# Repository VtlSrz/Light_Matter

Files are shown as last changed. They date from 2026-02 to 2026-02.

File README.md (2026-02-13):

# 📸 Light_Matter

Це DIY проект компактного та точного цифрового експонометра для плівкових фотокамер. Проект базується на мікроконтролері **ESP32-C3 Super Mini** та високоточному датчику освітленості **BH1750**.

Пристрій розроблено як сучасну заміну старим селеновим експонометрам або для використання з камерами, що не мають вбудованого заміру експозиції.

## ✨ Особливості та можливості

* **Режими роботи:**
* **Пріоритет діафрагми (Aperture Priority):** Ви обираєте діафрагму — пристрій підбирає витримку.
* **Пріоритет витримки (Shutter Priority):** Ви обираєте час витримки — пристрій підбирає діафрагму.

* **Широкий діапазон налаштувань:**
* **ISO:** 6 – 12800 (підтримка як сучасних, так і старих плівок).
* **Діафрагма (F):** f/0.7 – f/64 (включаючи вінтажні значення типу f/3.5, f/6.3).
* **Витримка (T):** 1/8000 с – 30 с.

* **Калібрування (EV Shift):** Можливість програмної корекції експозиції (від -3.0 EV до +3.0 EV) для компенсації особливостей простроченої плівки або похибок затвора камери.
* **Інформативний дисплей:**
* Відображення поточних LUX та розрахованого EV.
* Індикація застосованої експокорекції.
* Зручний інтерфейс з великими цифрами.

* **Меню налаштувань:**
* Регулювання яскравості дисплея (5 рівнів).
* Стиль відображення батареї (Іконка / Відсотки / Вольтаж).
* Налаштування таймера сну (Deep Sleep).
* Налаштування орієнтації єкрану.
* Можливість оновлення через WIFI (Elegant OTA).

* **Енергоефективність:**
* Використання Deep Sleep режиму ESP32.
* Автоматичне збереження всіх налаштувань в енергонезалежну пам'ять (Preferences/EEPROM).

* **Живлення:** LiPo акумулятор з можливістю зарядки та моніторингу напруги.

## 🛠 Компоненти (BOM)

| Компонент | Кількість | Примітка |
| --- | --- | --- |
| **ESP32-C3 Super Mini** | 1 | Основний контролер |
| **OLED SSD1306** | 1 | 0.96", 128x64, I2C |
| **BH1750** | 1 | Датчик освітленості (модуль) |
| **LX-LCBST** | 1 | Плата 2-в-1: зарядка LiPo + підвищувач на 5V |
| **LiPo Акумулятор** | 1 | 3.7V, 500mAh (або аналогічний) |
| **Тактова кнопка** | 2 | Керування (Menu / Change) |
| **Резистор 100 kΩ** | 2 | Для дільника напруги (моніторинг батареї) |
| **Дроти, корпус** | - | Для монтажу |

## 🔌 Схема підключення (Pinout)

### 1. Периферія

| Компонент | Пін компонента | Пін ESP32-C3 | Примітка |
| --- | --- | --- | --- |
| **OLED & BH1750** | SDA | **GPIO 8** | Шина I2C |
| | SCL | **GPIO 9** | Шина I2C |
| | VCC | 3.3V | Живлення логіки |
| | GND | GND | Земля |
| **Кнопка Menu** | Pin 1 | **GPIO 2** | Вхід в меню / Вибір параметра |
| | Pin 2 | GND | |
| **Кнопка Change** | Pin 1 | **GPIO 3** | Зміна значення |
| | Pin 2 | GND | | 

### 2. Система живлення та моніторингу батареї

Для живлення використовується плата **LX-LCBST**, яка заряджає акумулятор та підвищує напругу до 5V для стабільної роботи ESP32.

* **Акумулятор (LiPo):** Підключається до входів `BAT+` та `BAT-` плати LX-LCBST.
* **Живлення ESP32:** Вихід `VOUT` (5V) плати LX-LCBST підключається до піна `5V` (або VCC) на ESP32. Земля — спільна.
* **Вимірювання заряду:** Реалізовано через дільник напруги (2 резистори по 100 кОм), підключений безпосередньо до клем акумулятора (до підвищувача напруги).

```
   [LiPo BAT+] ----+---- [Резистор 100k] ---- GPIO 0 (ADC)
                   |           |
                   |     [Резистор 100k] ---- GND
                   |           |
             [LX-LCBST IN+]    

```

## 📖 Інструкція користувача

exponometer_scheme

## 🖥️ Інтерфейс користувача (UI)

Пристрій використовує монохромний OLED дисплей 128x64. Навігація інтуїтивно зрозуміла і здійснюється двома кнопками.
Параметри обираються нопкою **MENU** (верхня), зміна значень — кнопкою **NEXT** (нижня).
**Вибір параметра:** Коротке натискання **MENU** переміщує курсор `>` циклічно:

### 1. Головний екран (Режим вимірювання)

На головному екрані відображаються поточні показники датчика та параметри експозиції. Курсор `>` вказує на параметр, який зараз можна змінити.

**Приклад 1: Пріоритет діафрагми (F), EV Shift вимкнено, індикація заряду (Volt)**

```text
+--------------------------+
| lux540    EV12     4.01V |  <- Верхній статус-бар
|                          |
|    T 1/500               |  <- Розрахована витримка
| >  F 5.6                 |  <- Активний параметр (Діафрагма)
|                          |
|                  ISO 200 |  <- Чутливість
+--------------------------+

```

**Приклад 2: Пріоритет витримки (T), ввімкнено EV Shift (+1.0), індикація щаряду %**
Якщо застосована експокорекція (для старої плівки), її значення з'являється над ISO.

```text
+--------------------------+
| lux250    EV10       95% |
|                          |
| >  T 1/60                |  <- Активний параметр (Витримка)
|    F 4.0                 |  <- Розрахована діафрагма
|                     +1.0 |  <- Індикатор EV Shift
|                  ISO 400 |  <- ISO обрано (інверсний колір)
+--------------------------+

```

---

### 2. Меню налаштувань
Щоб увійти в налаштування, натисніть та утримуйте кнопку **MENU** протягом **2 секунд**. 
Обраний пункт підсвічується інверсією (біла смуга, чорний текст).

**Приклад 3: Початок списку меню**

```text
+--------------------------+
|     --- SETTINGS ---     |  <- Заголовок
|   Calib EV: +1.0         |  <- Обраний пункт (Експокорекція) * **Calib EV:** Експокорекція для старих плівок (від -3.0 до +3.0). Якщо значення відмінне від 0, над ISO з'явиться індикатор (напр. `+1.0`).
| [ Bright: 3            ] |  <- Обраний пункт (Яскравість) * **Bright:** Яскравість дисплея (1 — мін, 5 — макс).
|   Bat Ind: Volt          |  <- Обраний пункт (Заряд) * **Bat Ind:** Вигляд індикатора батареї (Icon / % / Voltage).
|   Sleep: Never           |  <- Обраний пункт (СОН) * **Sleep:** Таймер автовимкнення (від 3 сек до 1 години або вимкнено).
+--------------------------+

```

**Приклад 4: Прокрутка меню вниз (активація WiFi)**
Коли ви рухаєтесь нижче 4-го пункту, меню прокручується.

```text
+--------------------------+
|     --- SETTINGS ---     |
|   Sleep: 1 min           |
|   Rotate: 0 deg          |  <- Обраний пункт (Орієнтація) * **Rotate:** Переворот на 180*, зміна орієнтації дисплея (0-180*) .
| [ WiFi Service         ] |  <- Обраний пункт (Оновлення) * **WiFi Service:** Запуск вайфай точки доступу, оновлення прошивки пристрою.
|   EXIT / BACK            |  <- Обраний пункт (Назад) * **EXIT / BACK:** Плвернення на головний єкран, авто-вихід із меню налаштувань - 10сек, Всі налаштування зберігаються після вимкнення.
+--------------------------+

```

---

### 3. Режим WiFi Service (Оновлення прошивки)

Цей екран з'являється після активації "WiFi Service" в меню. Він показує дані для підключення для OTA-оновлення.

```text
+--------------------------+
| --- WIFI SERVICE ---     |
|                          |
| SSID: Light_Matter       |
| PASS: 12345678           |
| IP:   192.168.4.1        |
|                          |
| [ PRESS MENU TO EXIT ]   |
+--------------------------+

```
Створюється вайфай точка доступу з імʼям - Light_Matter  та паролем - 12345678 . 
Після підключення потрібно ввести в браузері в поле url  - 192.168.4.1/update , 
Відкриється веб сторінка для оновлення прошивки .bin файлами. 
Натиск кнопки Menu або Next повертає до головного єкрану. 

##  Зарядка

Для живлення пристрою використовується lipo аккумулятор на 350мА. Час роботи - до 7 годин. 
Зарядка - 5V 1A блочком. Час зарядки 30хв. При зарядці на нижній кришці горить червоний led, при повній зарядці led горить синім кольором. 
Можна заряджати від павербанку, підтримується роботаа експонометра під час зарядки. 

## 💻 Прошивка

Проект написано в середовищі **Arduino IDE**. та використанням Gemini. 

### Необхідні бібліотеки:

Встановіть наступні бібліотеки через Library Manager:

1. **Adafruit SSD1306** (by Adafruit)
2. **Adafruit GFX Library** (by Adafruit)
3. **BH1750** (by Christopher Laws)
4. **OneButton** (by Matthias Hertel)

### Налаштування плати в Arduino IDE:

* **Board:** ESP32C3 Dev Module
* **USB CDC On Boot:** Enabled
* **Flash Mode:** DIO

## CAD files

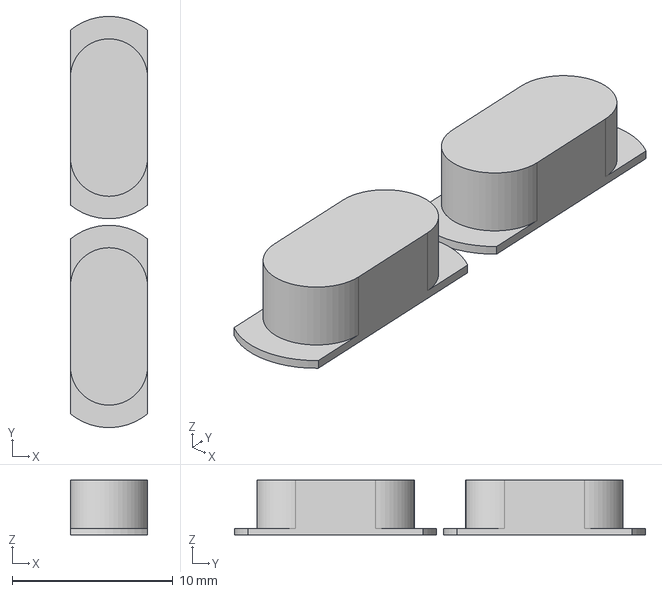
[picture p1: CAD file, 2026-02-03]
3d/buttons.step
4.80 x 25.6 x 3.40 mm

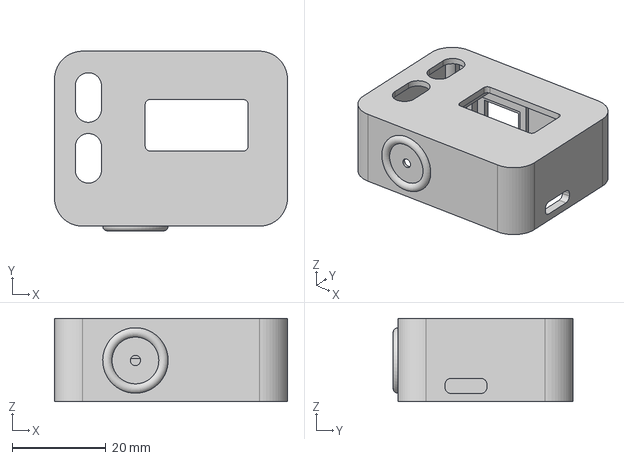
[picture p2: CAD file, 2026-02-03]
3d/case.step
49.8 x 38.4 x 17.8 mm

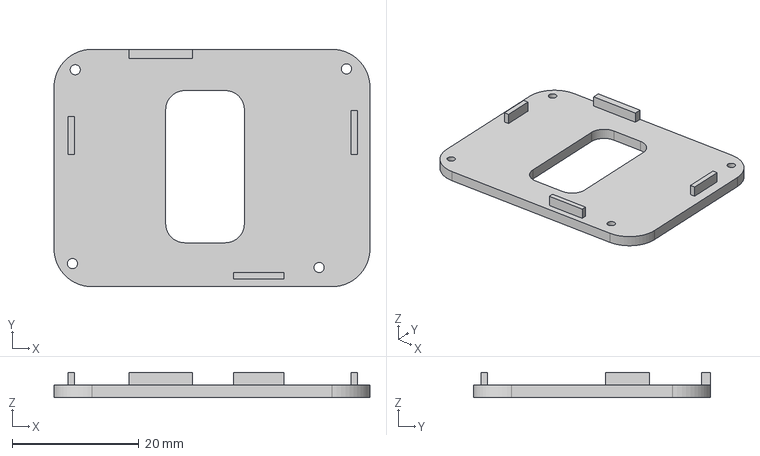
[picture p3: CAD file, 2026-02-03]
3d/back.step
49.8 x 37.4 x 4.00 mm

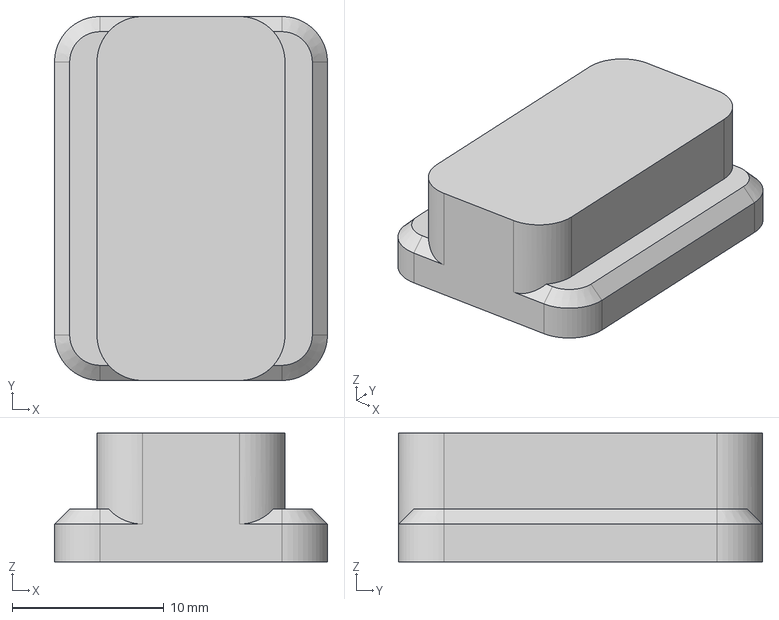
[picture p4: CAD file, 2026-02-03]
3d/shoe.step
18.0 x 24.0 x 8.50 mm

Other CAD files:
3d/front.step

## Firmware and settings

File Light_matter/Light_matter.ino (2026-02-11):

#include <Wire.h>
#include <Adafruit_GFX.h>
#include <Adafruit_SSD1306.h>
#include <BH1750.h>
#include <OneButton.h>
#include <Preferences.h>

// --- WIFI & OTA ---
#include <WiFi.h>
#include <WebServer.h>
#include <ElegantOTA.h>

// --- ПІНИ ---
#define PIN_BATTERY 0
#define PIN_BTN_MENU 1    
#define PIN_BTN_CHANGE 2  

// --- ДИСПЛЕЙ ---
#define SCREEN_WIDTH 128
#define SCREEN_HEIGHT 64
Adafruit_SSD1306 display(SCREEN_WIDTH, SCREEN_HEIGHT, &Wire, -1);

// --- ДАТЧИК ---
BH1750 lightMeter;

// --- ПАМ'ЯТЬ ---
Preferences prefs;

// --- WEB SERVER ---
WebServer server(80);

// --- КНОПКИ ---
OneButton btnMenu(PIN_BTN_MENU, true);
OneButton btnChange(PIN_BTN_CHANGE, true);

// --- СТАНИ ---
enum AppState { STATE_MAIN, STATE_MENU, STATE_WIFI_SERVICE };
AppState currentState = STATE_MAIN;

// --- ЗМІННІ ---
const float dividerRatio = 2.0; 
int selectedIndex = 1; 
int lockMode = 1; 

float currentLux = 0;     
float accumulatedLux = 0; 
int sampleCount = 0;      
float currentEV = 0;

// --- НАЛАШТУВАННЯ ---
int settingsBrightness = 2; 
int settingsBatStyle = 0;   
int settingsSleepIdx = 5;   
int settingsEvShift = 0;    
int settingsRotate = 0;     

unsigned long lastActivityTime = 0; 
unsigned long lastLuxUpdate = 0; 

// --- МАСИВИ ---
const float fStops[] = { 0.7, 0.8, 0.9, 0.95, 1.0, 1.1, 1.2, 1.4, 1.6, 1.7, 1.8, 2.0, 2.2, 2.4, 2.5, 2.8, 3.2, 3.5, 4.0, 4.5, 4.8, 5.0, 5.6, 6.3, 6.7, 7.1, 8.0, 9.0, 9.5, 10, 11, 12.5, 13, 14, 16, 18, 19, 20, 22, 25, 29, 32, 36, 40, 45, 51, 57, 64 };
const int fStopCount = sizeof(fStops) / sizeof(fStops[0]);

const float shutterSpeeds[] = { 8000, 6400, 5000, 4000, 3200, 2500, 2000, 1600, 1250, 1000, 800, 640, 500, 400, 320, 250, 200, 160, 125, 100, 80, 60, 50, 40, 30, 25, 20, 15, 13, 10, 8, 6, 5, 4, 3, 2.5, 2, 1.6, 1.3, -1, -1.3, -1.6, -2, -2.5, -3, -4, -5, -6, -8, -10, -13, -15, -20, -25, -30 };
const int shutterCount = sizeof(shutterSpeeds) / sizeof(shutterSpeeds[0]);

const int isoValues[] = { 6, 12, 25, 50, 64, 80, 100, 125, 160, 200, 250, 320, 400, 500, 640, 800, 1000, 1250, 1600, 2000, 2500, 3200, 6400, 12800 };
const int isoCount = sizeof(isoValues) / sizeof(isoValues[0]);

const long sleepTimes[] = { 0, 3000, 5000, 10000, 30000, 60000, 180000, 300000, 600000, 900000, 1800000, 3600000 };
const char* sleepLabels[] = { "Never", "3 sec", "5 sec", "10 sec", "30 sec", "1 min", "3 min", "5 min", "10 min", "15 min", "30 min", "1 hour" };
const int sleepTimesCount = 12;

int isoIdx = 6;       
int apertureIdx = 22; 
int shutterIdx = 18;  

// --- ЗМІННІ МЕНЮ ---
int menuIndex = 0; 
int menuScrollTop = 0; 
const int menuItemsCount = 7; 
const int menuVisibleItems = 4;

// --- ФУНКЦІЇ ---

void setBrightness(int level) {
  int contrast = 0;
  switch(level) {
    case 0: contrast = 1; break;   
    case 1: contrast = 60; break;  
    case 2: contrast = 127; break; 
    case 3: contrast = 190; break; 
    case 4: contrast = 255; break; 
    default: contrast = 127; break;
  }
  display.ssd1306_command(SSD1306_SETCONTRAST);
  display.ssd1306_command(contrast);
}

void applyRotation() {
  if (settingsRotate == 1) display.setRotation(2); 
  else display.setRotation(0);
}

void loadPreferences() {
  prefs.begin("meter", false);
  isoIdx = prefs.getInt("iso", 6);
  apertureIdx = prefs.getInt("aperture", 22);
  settingsBrightness = prefs.getInt("bright", 2);
  settingsBatStyle = prefs.getInt("batstyle", 0);
  settingsSleepIdx = prefs.getInt("sleep", 5); 
  settingsEvShift = prefs.getInt("evshift", 0); 
  settingsRotate = prefs.getInt("rotate", 0);
  
  setBrightness(settingsBrightness);
}

void savePreferences() {
  prefs.putInt("iso", isoIdx);
  prefs.putInt("aperture", apertureIdx);
  prefs.putInt("bright", settingsBrightness);
  prefs.putInt("batstyle", settingsBatStyle);
  prefs.putInt("sleep", settingsSleepIdx);
  prefs.putInt("evshift", settingsEvShift);
  prefs.putInt("rotate", settingsRotate);
}

void goToSleep() {
  display.clearDisplay();
  display.display();
  display.ssd1306_command(SSD1306_DISPLAYOFF);
  savePreferences();
  esp_deep_sleep_enable_gpio_wakeup((1ULL << PIN_BTN_MENU) | (1ULL << PIN_BTN_CHANGE), ESP_GPIO_WAKEUP_GPIO_LOW);
  esp_deep_sleep_start();
}

float getShutterTime(float val) {
  if (val < 0) return abs(val);
  return 1.0 / val;
}

int roundToTen(float val) {
  if (val < 10) return (int)val; 
  return (int)((val + 5.0) / 10.0) * 10;
}

String getEvShiftString() {
  if (settingsEvShift == 0) return "0.0";
  float val = settingsEvShift / 3.0;
  String s = (val > 0) ? "+" : "";
  s += String(val, 1);
  return s;
}

void startWiFiService() {
  WiFi.mode(WIFI_AP);
  WiFi.softAP("Light_Matter", "12345678");
  
  server.on("/", []() {
    server.send(200, "text/plain", "Light Matter OTA Service. Go to /update");
  });

  ElegantOTA.begin(&server);    
  server.begin();
  
  currentState = STATE_WIFI_SERVICE;
}

void stopWiFiService() {
  server.stop();
  WiFi.softAPdisconnect(true);
  WiFi.mode(WIFI_OFF);
  currentState = STATE_MENU; 
}

// --- CALLBACKS ---

void clickMenu() {
  lastActivityTime = millis(); 
  
  if (currentState == STATE_MAIN) {
    if (selectedIndex == 1) selectedIndex = 0;      
    else if (selectedIndex == 0) selectedIndex = 2; 
    else selectedIndex = 1;                         
    calculateExposure(); 
    drawMainScreen();
  } 
  else if (currentState == STATE_MENU) {
    menuIndex = (menuIndex + 1) % menuItemsCount;
    // SCROLL LOGIC
    if (menuIndex >= menuScrollTop + menuVisibleItems) {
      menuScrollTop = menuIndex - menuVisibleItems + 1;
    }
    if (menuIndex == 0) {
      menuScrollTop = 0;
    }
    drawMenuScreen();
  }
  else if (currentState == STATE_WIFI_SERVICE) {
    stopWiFiService();
    drawMenuScreen();
  }
}

void longPressMenu() {
  lastActivityTime = millis();
  
  if (currentState == STATE_MAIN) {
    currentState = STATE_MENU;
    menuIndex = 0;
    menuScrollTop = 0; 
    drawMenuScreen();
  } 
  else if (currentState == STATE_MENU) {
    currentState = STATE_MAIN;
    savePreferences(); 
    calculateExposure();
    drawMainScreen();
  }
  else if (currentState == STATE_WIFI_SERVICE) {
    stopWiFiService();
    drawMenuScreen();
  }
}

void clickChange() {
  lastActivityTime = millis();
  
  if (currentState == STATE_MAIN) {
    if (selectedIndex == 0) isoIdx = (isoIdx + 1) % isoCount;
    else if (selectedIndex == 1) { apertureIdx = (apertureIdx + 1) % fStopCount; lockMode = 1; }
    else if (selectedIndex == 2) { shutterIdx = (shutterIdx + 1) % shutterCount; lockMode = 2; }
    calculateExposure();
    drawMainScreen();
  } 
  else if (currentState == STATE_MENU) {
    // НОВИЙ ПОРЯДОК ПУНКТІВ
    switch(menuIndex) {
      case 0: // EV Shift
        settingsEvShift++; if (settingsEvShift > 9) settingsEvShift = -9; break;
      case 1: // Brightness
        settingsBrightness = (settingsBrightness + 1) % 5; setBrightness(settingsBrightness); break;
      case 2: // Bat Style
        settingsBatStyle = (settingsBatStyle + 1) % 3; break;
      case 3: // Sleep
        settingsSleepIdx = (settingsSleepIdx + 1) % sleepTimesCount; break;
      case 4: // Rotate
        settingsRotate = !settingsRotate; applyRotation(); break;
      case 5: // WiFi
        startWiFiService(); break;
      case 6: // Exit
        currentState = STATE_MAIN; savePreferences(); break;
    }
    if (currentState == STATE_MENU) drawMenuScreen(); 
  }
}

void setup() {
  Wire.begin(8, 9);
  if(!display.begin(SSD1306_SWITCHCAPVCC, 0x3C)) for(;;);
  
  pinMode(PIN_BTN_MENU, INPUT_PULLUP);
  pinMode(PIN_BTN_CHANGE, INPUT_PULLUP);
  
  btnMenu.attachClick(clickMenu);
  btnMenu.attachLongPressStart(longPressMenu);
  btnMenu.setPressTicks(2000); 
  btnChange.attachClick(clickChange);

  loadPreferences();
  applyRotation();

  selectedIndex = 1; 
  lockMode = 1;      
  
  lightMeter.begin(BH1750::CONTINUOUS_HIGH_RES_MODE);
  display.setTextColor(SSD1306_WHITE);
  
  lastActivityTime = millis();
  lastLuxUpdate = millis();
}

void calculateExposure() {
  if (currentLux <= 0) return;
  float ev100 = log10(currentLux / 2.5) / log10(2.0);
  float shiftedEV100 = ev100 - (settingsEvShift / 3.0);
  currentEV = shiftedEV100 + (log10((float)isoValues[isoIdx] / 100.0) / log10(2.0));

  if (lockMode == 1) { 
    float f = fStops[apertureIdx];
    float t_target = (f * f) / pow(2.0, currentEV);
    
    float minDiff = 1000000;
    int bestIdx = 0;
    for (int i = 0; i < shutterCount; i++) {
      float t_array = getShutterTime(shutterSpeeds[i]);
      float diff = abs(t_array - t_target);
      if (diff < minDiff) { minDiff = diff; bestIdx = i; }
    }
    shutterIdx = bestIdx;
  } else {
    float t_seconds = getShutterTime(shutterSpeeds[shutterIdx]);
    float f_target = sqrt(t_seconds * pow(2.0, currentEV));
    
    float minDiff = 100;
    int bestIdx = 0;
    for (int i = 0; i < fStopCount; i++) {
      float diff = abs(fStops[i] - f_target);
      if (diff < minDiff) { minDiff = diff; bestIdx = i; }
    }
    apertureIdx = bestIdx;
  }
}

void drawBattery(int x, int y) {
  float sum = 0; 
  for(int i=0; i<3; i++) sum += analogRead(PIN_BATTERY);
  
  // 3.04 corrected
  float voltage = (sum/3.0 * 3.04 / 4095.0) * dividerRatio;
  
  int percent = map(constrain(voltage * 100, 330, 420), 330, 420, 0, 100);
  
  if (settingsBatStyle == 1) {
    display.setCursor(x - 10, y); 
    display.print(percent); display.print("%");
  } else if (settingsBatStyle == 2) {
    display.setCursor(x - 18, y); 
    display.print(voltage, 2); display.print("V");
  } else {
    display.drawRect(x, y, 16, 8, SSD1306_WHITE);
    display.fillRect(x + 16, y + 2, 2, 4, SSD1306_WHITE);
    int w = map(percent, 0, 100, 0, 12);
    if(w > 0) display.fillRect(x+2, y+2, w, 4, SSD1306_WHITE);
  }
}

void drawMainScreen() {
  display.clearDisplay();
  int headerY = 4;

  // Header
  display.setTextSize(1);
  display.setCursor(0, headerY);
  display.print("lux"); display.print((int)currentLux);
  
  display.setCursor(60, headerY);
  display.print("EV"); display.print((int)currentEV);
  
  if (settingsEvShift != 0) {
    String shiftStr = getEvShiftString();
    int shiftX = 128 - (shiftStr.length() * 6);
    display.setCursor(shiftX, 46); 
    display.print(shiftStr);
  }

  drawBattery(110, headerY);

  int yCenter = 20;
  int xPadding = 12;

  // T
  if(selectedIndex == 2) { display.setCursor(0, yCenter + 4); display.print(">"); }
  display.setTextSize(2);
  display.setCursor(xPadding, yCenter);
  display.print("T ");
  float sVal = shutterSpeeds[shutterIdx];
  if (sVal > 0) { display.print("1/"); display.print((int)sVal); }
  else { display.print(abs(sVal), 1); display.print("\""); }

  // F
  if(selectedIndex == 1) { display.setTextSize(1); display.setCursor(0, yCenter + 26); display.print(">"); }
  display.setTextSize(2);
  display.setCursor(xPadding, yCenter + 22);
  display.print("F ");
  display.print(fStops[apertureIdx], 1); 

  // ISO
  display.setTextSize(1);
  int isoVal = isoValues[isoIdx];
  int charCount = 4; if(isoVal<100) charCount+=2; else if(isoVal<1000) charCount+=3; else if(isoVal<10000) charCount+=4; else charCount+=5;
  int xPos = 128 - (charCount * 6);
  
  display.setCursor(xPos, 56);
  if(selectedIndex == 0) display.setTextColor(SSD1306_BLACK, SSD1306_WHITE);
  display.print("ISO "); display.print(isoVal);
  display.setTextColor(SSD1306_WHITE);

  display.display();
}

void drawWiFiScreen() {
  display.clearDisplay();
  display.setTextSize(1);
  display.setCursor(0, 0);
  display.println("--- WIFI SERVICE ---");
  display.setCursor(0, 12);
  display.println("SSID: Light_Matter");
  display.setCursor(0, 24);
  display.println("PASS: 12345678");
  display.setCursor(0, 36);
  display.println("IP:   192.168.4.1");
  display.fillRect(0, 52, 128, 12, SSD1306_WHITE);
  display.setTextColor(SSD1306_BLACK);
  display.setCursor(15, 54);
  display.print("PRESS MENU TO EXIT");
  display.setTextColor(SSD1306_WHITE);
  display.display();
}

// НОВЕ ІНВЕРСИВНЕ МЕНЮ
void drawMenuScreen() {
  display.clearDisplay();
  
  display.setTextSize(1);
  // Зміщений заголовок
  display.setCursor(20, 4); 
  display.print("--- SETTINGS ---");
  
  int yBase = 14; 
  int lineHeight = 12; 
  int textOffset = 2; // Менший відступ бо нема курсора

  for (int i = 0; i < menuVisibleItems; i++) {
    int itemIndex = menuScrollTop + i;
    
    if (itemIndex >= menuItemsCount) break;

    int yPos = yBase + (i * lineHeight);

    // ІНВЕРСІЯ ВИДІЛЕННЯ
    if (itemIndex == menuIndex) {
      // Малюємо білий прямокутник фону
      display.fillRect(0, yPos - 1, 128, lineHeight, SSD1306_WHITE);
      // Колір тексту - чорний
      display.setTextColor(SSD1306_BLACK);
    } else {
      // Колір тексту - білий
      display.setTextColor(SSD1306_WHITE);
    }

    display.setCursor(textOffset, yPos);

    // НОВИЙ ПОРЯДОК ПУНКТІВ
    switch (itemIndex) {
      case 0:
        display.print("Calib EV: ");
        display.print(getEvShiftString());
        break;
      case 1:
        display.print("Bright: ");
        display.print(settingsBrightness + 1);
        break;
      case 2:
        display.print("Bat Ind: ");
        if(settingsBatStyle == 0) display.print("Icon");
        else if(settingsBatStyle == 1) display.print("%");
        else display.print("Volt");
        break;
      case 3:
        display.print("Sleep: ");
        display.print(sleepLabels[settingsSleepIdx]);
        break;
      case 4:
        display.print("Rotate: ");
        if (settingsRotate == 0) display.print("0 deg");
        else display.print("180 deg");
        break;
      case 5:
        display.print("WiFi Service");
        break;
      case 6:
        display.print("EXIT / BACK");
        break;
    }
  }
  
  // Повертаємо стандартний колір для наступних малювань (header, etc)
  display.setTextColor(SSD1306_WHITE);

  display.display();
}

void loop() {
  btnMenu.tick();
  btnChange.tick();
  
  if (currentState == STATE_WIFI_SERVICE) {
    server.handleClient();
    ElegantOTA.loop();
  }
  
  unsigned long currentMillis = millis();

  // Sleep logic
  long sleepDuration = sleepTimes[settingsSleepIdx];
  if (currentState == STATE_MAIN && sleepDuration > 0 && (currentMillis - lastActivityTime > sleepDuration)) {
    goToSleep();
  }
  
  // Auto exit menu
  if (currentState == STATE_MENU && (currentMillis - lastActivityTime > 15000)) {
    currentState = STATE_MAIN; 
    savePreferences();
    drawMainScreen();
  }

  // Sensor reading
  static unsigned long lastSampleTime = 0;
  if (currentMillis - lastSampleTime > 100) { 
    float val = lightMeter.readLightLevel();
    if (val >= 0) {
      accumulatedLux += val;
      sampleCount++;
    }
    lastSampleTime = currentMillis;
  }

  if (currentState == STATE_MAIN) {
    if (currentMillis - lastLuxUpdate > 1000) {
      if (sampleCount > 0) {
        float avgLux = accumulatedLux / sampleCount;
        currentLux = roundToTen(avgLux);
        accumulatedLux = 0;
        sampleCount = 0;
        calculateExposure();
        drawMainScreen();
      }
      lastLuxUpdate = currentMillis;
    }
  } 
  else if (currentState == STATE_WIFI_SERVICE) {
    static unsigned long lastWiFiDraw = 0;
    if (currentMillis - lastWiFiDraw > 1000) {
      drawWiFiScreen();
      lastWiFiDraw = currentMillis;
    }
  }
  else { // STATE_MENU
    static unsigned long lastMenuUpdate = 0;
    if (currentMillis - lastMenuUpdate > 100) {
       drawMenuScreen();
       lastMenuUpdate = currentMillis;
    }
  }
}

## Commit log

2026-02-03 3d. files
    [back.step, buttons.step, case.step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]
2026-02-06 Update Light_matter.ino
    Додано: Elegant OTA для оновлення прошивки вже зібраного експонометра
    Додано: налаштування перевороту єкрану
2026-02-11 README.md
    Оновив описи дисплею та інтерфейсу
